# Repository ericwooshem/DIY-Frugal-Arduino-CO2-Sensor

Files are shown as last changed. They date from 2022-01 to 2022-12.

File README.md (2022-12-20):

# DIY Frugal Arduino CO₂ Sensor Monitor

CC BY-NC-SA [Eric Woo-Shem](https://github.com/ericwooshem) & [Brian Woo-Shem](https://www.brianwooshem.com)

CO2 Sensor Several Different Makes CO2 Data Graph

## Features

- Displays the current CO₂ level so you can quickly check if the current conditions are safe. 
- Records CO₂ levels over time. Good for tracking regularly-scheduled events (eg. school & work). 
- Accurate within ~60 ppm under typical conditions.
- Costs $60 to $110 - less than half the cost of commercial sensors.
- No soldering required! Just connect wires.

## Introduction: Why measure CO₂?

As society reopens amid the ongoing COVID-19 pandemic, preventing the spread of the virus is crucial to keeping doors open. Scientists and engineers studying aerosols at major research institutions have identified that good ventilation plays a major role in reducing contagion in addition to vaccines, regular testing, and masks [1]. Since [COVID-19 spreads primarily through airborne virus particles](https://www.science.org/doi/10.1126/science.abd9149), outdoor and well-ventilated areas are much safer because infectious particles blow away before they can be inhaled by a susceptible person. The challenge is identifying which spaces are poorly ventilated and could contain high concentrations of the virus.

Ideally, we would measure the concentration of COVID-19 virus particles in the air directly, however such a sensor does not exist. Instead, researchers identified [carbon dioxide as a proxy measurement](https://www.washingtonpost.com/health/2021/02/10/carbon-dioxide-device-coronavirus/) to determine if a space is well-ventilated, as doubling the CO₂ concentration doubles the risk of infection [2][3]. Humans exhale carbon dioxide at approximately 100 times the concentration of the ambient air. High CO₂ levels indicate inadequate ventilation so if a contagious person were present, virus particles remain in the air and there is a high risk that others in the space will get sick. 

The typical outdoor air CO₂ levels are between 410-420 ppm in remote locations, and around 450 ppm in urban environments [4][16]. We exhale roughly 40000 ppm CO₂ [5]. Aerosol researchers recommend keeping CO₂ below 800 ppm to prevent the spread of COVID-19 [1][2][3][6]. Aside from the pandemic, elevated CO₂ levels make a room feel “stuffy” and can cause a decline in cognitive ability [7]. CO₂ sensing is used in Heating, Ventilation, and Air Conditioning (HVAC) control and energy-saving thermostats to detect when a room is occupied and only operate air conditioning or heating during those times [14][15]. This can save energy by not running equipment while a building is unoccupied, while ensuring that people in the building have clean, healthy air [14].

# Instructions

### Parts

This is a *frugal* CO₂ sensor so most of the parts can be interchanged with similar ones. A detailed Bill of Materials with the exact components used in this version of the sensor is provided as "[CO2_Sensor_Bill_of_Materials.xlsx](https://github.com/ericwooshem/DIY-Frugal-Arduino-CO2-Sensor/blob/main/CO2_Sensor_Bill_of_Materials.xlsx)". Different sheets show suggestions for products to purchase for the lowest cost for varying numbers of sensors. The quantities and exact cost autocompute if you plug in the number of sensors you want to build. 

**Note:** Product suggestions in Bill of Materials are for convenience only. This project does not receive any incentive, financial or otherwise, for suggesting any particular product.

#### Cost

One sensor can be built for roughly $100, and 10 sensors for about $87 each if all parts are purchased new (As of August 2021).

#### List of Parts

| Part Description | QTY per Sensor |
|---|---|
| Arduino: Nano (recommended), Uno, Mega, etc. | 1|
|[SCD-30 NDIR CO2 Sensor](http://www.adafruit.com/product/4867)| 1|
|[STEMMA QT Cable Headers for SCD-30](http://www.adafruit.com/product/4209)|1|
|Breadboard: Mini breadboards recommended, but any size can work|1-2|
|Micro SD Card Adapter Module (Or SD Card Adapter Module)|1|
| Micro SD (or SD) Card. Small is fine - 1 GB is overkill|1|
|DS3231 Real Time Clock Module|1|
| CR2032 Battery|1|
|Jumper wires, assorted|10-20|
|USB Power Bank Battery 5V: optional; 9V battery adapter or other power supplies work as well|1|
|16x2 LCD Display: Optional; only needed if you want to display the current CO₂ levels|1|
|Small Box: Cardboard, 3D printed, etc. Just large enough to hold everything, and with holes for the CO₂ sensor intake and LCD screen if used|1|

## Assembly

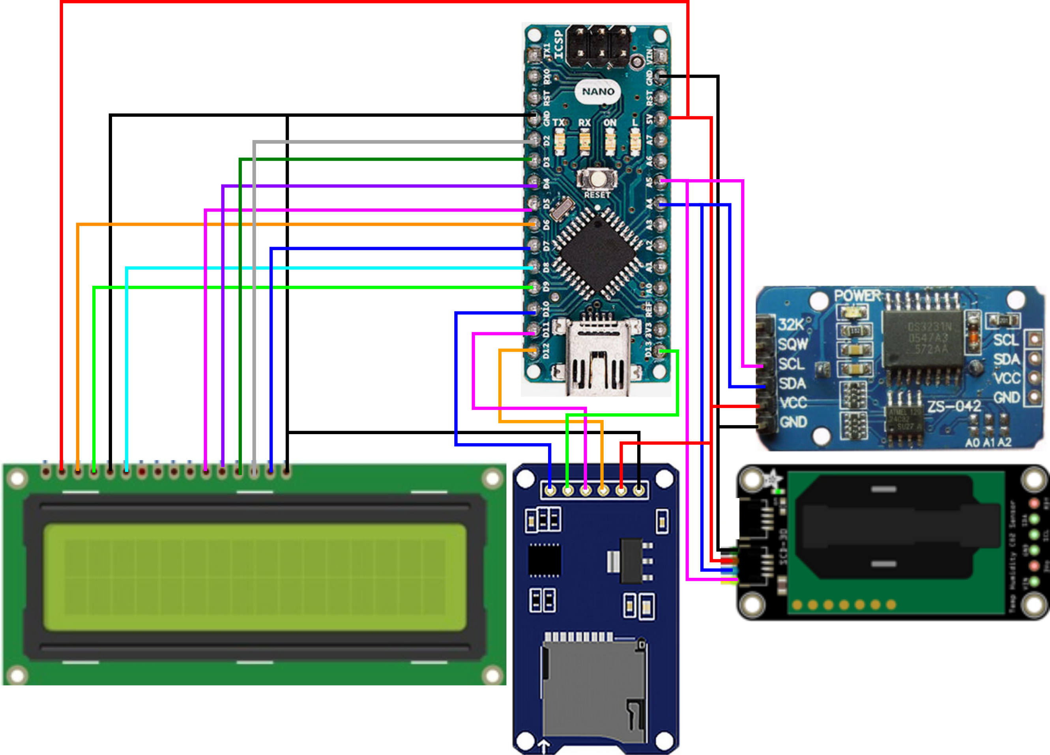
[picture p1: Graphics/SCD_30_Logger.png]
Connection Diagram


Complete connection diagram.

1. Insert the CR2032 battery into the RTC, and your memory card into your card reader.

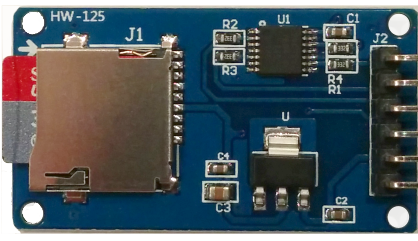
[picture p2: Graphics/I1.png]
Micro SD
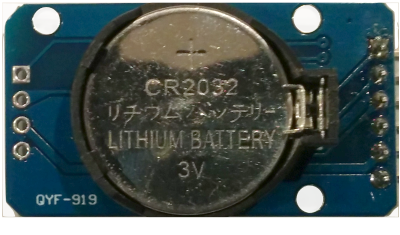
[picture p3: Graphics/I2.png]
RTC
	 

2. Attach 4 male-to-female wires onto the GND, VCC, SDA, and SCL ports on the RTC. If you have a new set of jumper wires, you may need to break them off of the bundle. Wire colors may vary.

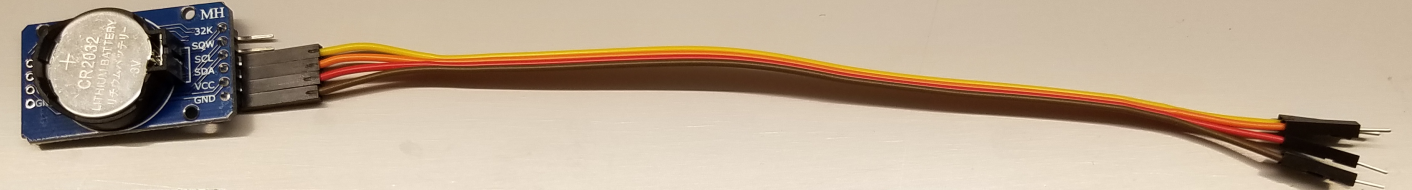
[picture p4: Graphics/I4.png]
	

3. Attach 6 male-to-female wires for all 6 pins on the card reader.

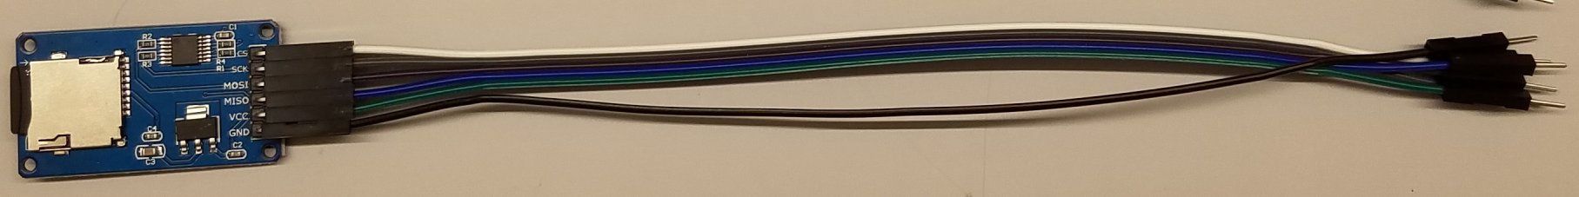
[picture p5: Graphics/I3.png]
Card Reader Wires
	

4. (For Nano only) Place and push in the Arduino Nano into one of the breadboards, as shown.

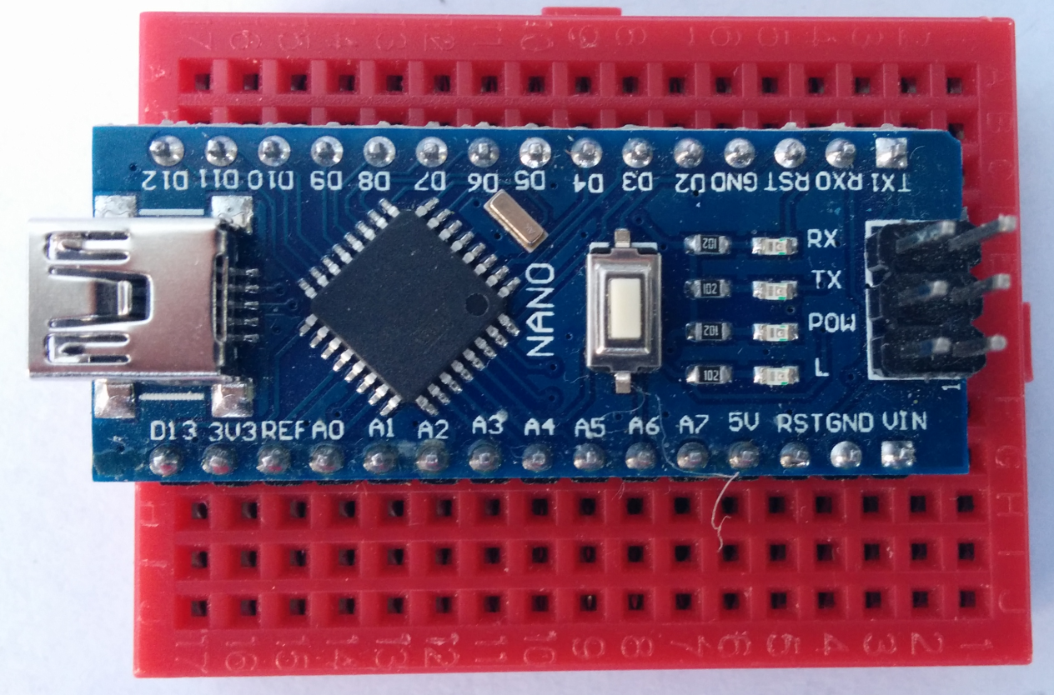
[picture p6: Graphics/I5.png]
Arduino Nano Breadboard
	

	- (For Uno or Mega) The connectors are built in, so this step is not necessary. However, you may need to run a wire from a particular pin to a breadboard row if more than one connection is required.  

5. Plug the SCD-30 cable headers into either port of the CO₂ sensor. Both ports are identical, but the plug has a correct orientation.

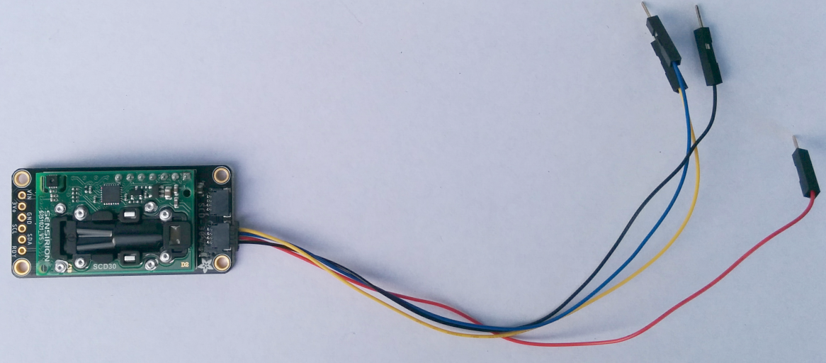
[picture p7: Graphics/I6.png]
SCD-30 Cable
	

6. (If using display) Poke the LCD into a breadboard. Mini-breadboards: use a second breadboard. Note: you can also use male-to-female wires and connect to the LCD pins directly, but we found this to be more difficult.

7. Connect the Ground on the Arduino to an unused row on the breadboard. Connect the 5V on the Arduino to a different unused row. Below is an example for mini-breadboards.

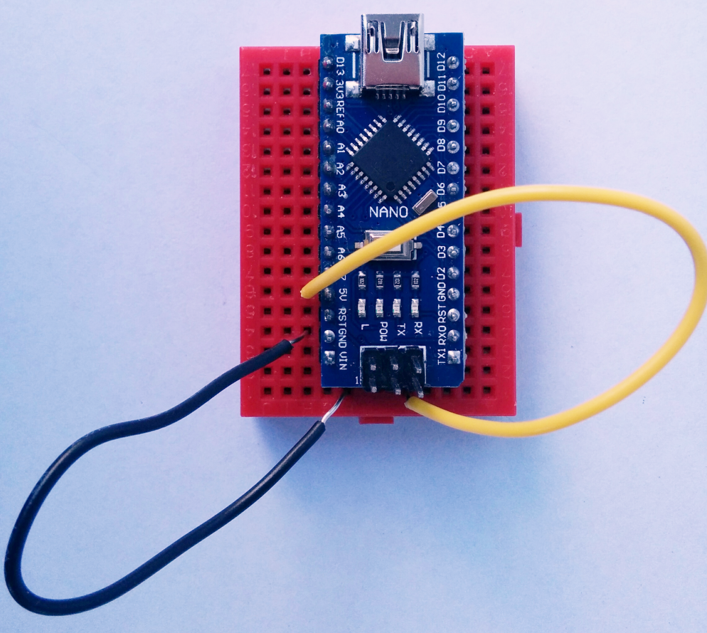
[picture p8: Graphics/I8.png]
Arduino-Breadboard
	

8. Connect the Real Time Clock module wires:

|Sensor Wire|Breadboard Row|
|---|---|
|VCC | 5V row created in step 7|
|GND | the ground row created in step 7|
|SDA | Arduino pin A4|
|SCL | Arduino pin A5|

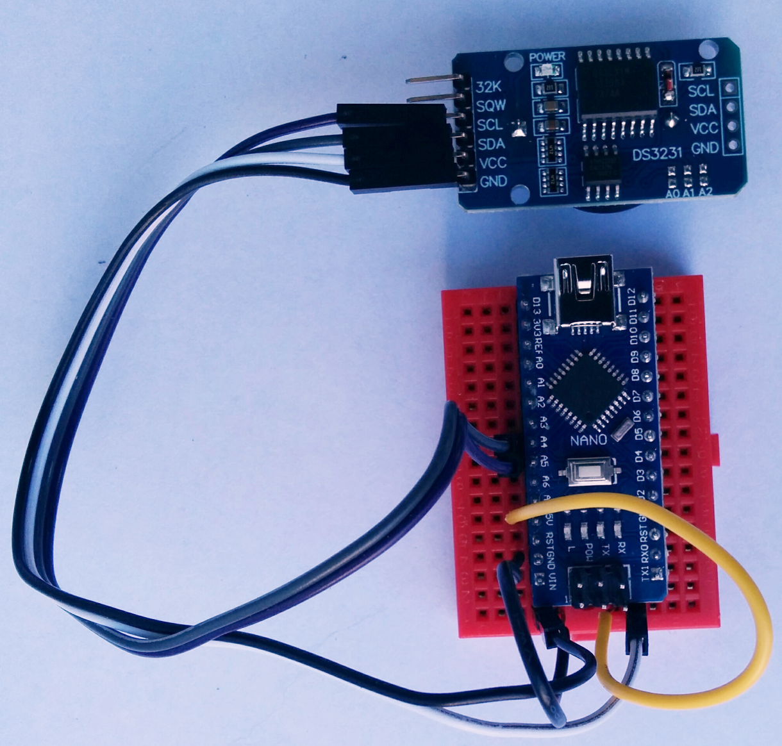
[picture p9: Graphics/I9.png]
   

9. Connect the SD Card Reader wires:

|Sensor Wire|Breadboard Row|
|---|---|
|GND |ground row created in step 7|
|VCC | 5V row created in step 7|
|MISO | Arduino pin D12|
|MOSI | Arduino pin D11|
|SCK | Arduino pin D13|
|CS | Arduino pin D10|

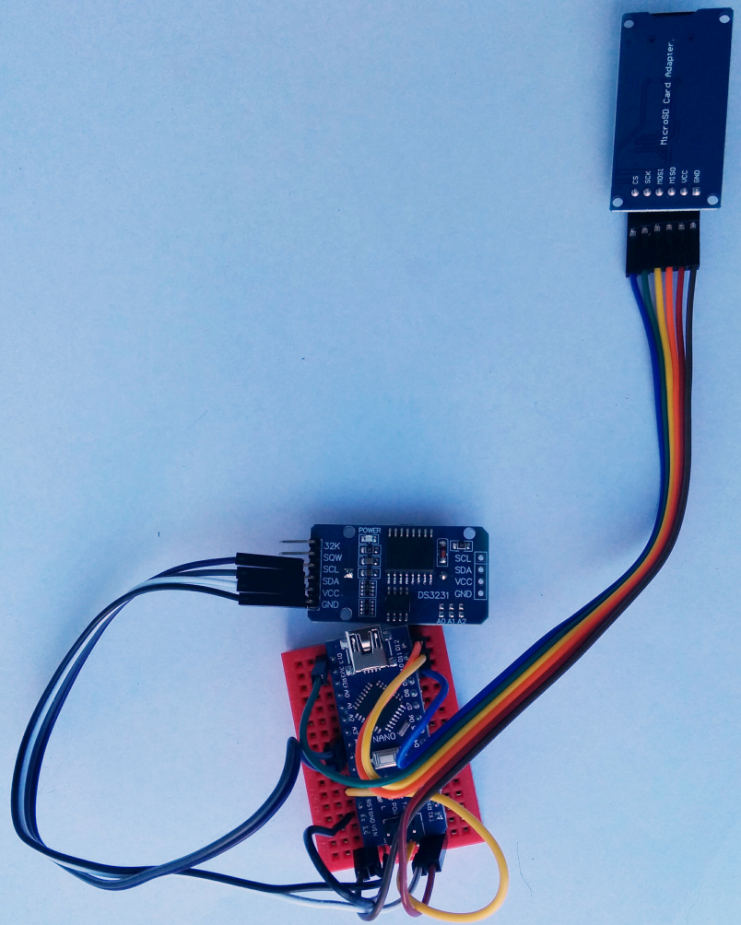
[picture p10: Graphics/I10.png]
SD Wires


10. Connect the SCD-30 Sensor wires:

|Sensor Wire|Breadboard Row|
|---|---|
|Black| ground row created in step 7|
|Red| 5V row created in step 7|
|Blue| Arduino pin A4|
|Yellow| Arduino pin A5|

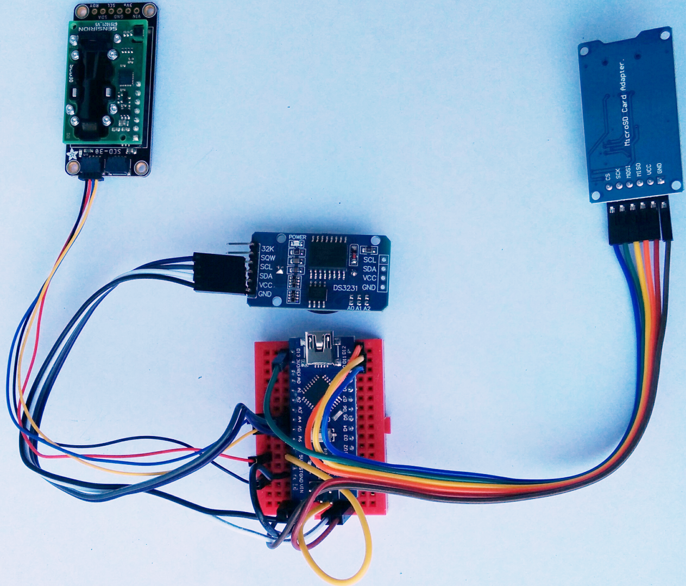
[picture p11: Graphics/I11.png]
SCD-30 Wires


11. Connect the LCD Wires: Short wires cut to length are preferred because they are more robust and make the device more compact. If using mini-breadboards, connect the LCD breadboard to the digital pin side of the Arduino breadboard using the little clip. Long wires are no longer recommended because they tend to get snagged and fall out. 

|LCD Pin Label|LCD Pin Position (Left to right)|Arduino Pin|
|---|---|---|
|VDD|2|5V|
|V0|3|D6|
|RS|4|D9|
|RW|5|Ground|
|E|6|D8|
|D4|11|D5|
|D5|12|D4|
|D6|13|D3|
|D7|14|D2|
|A|15|D7|
|K|16|Ground|

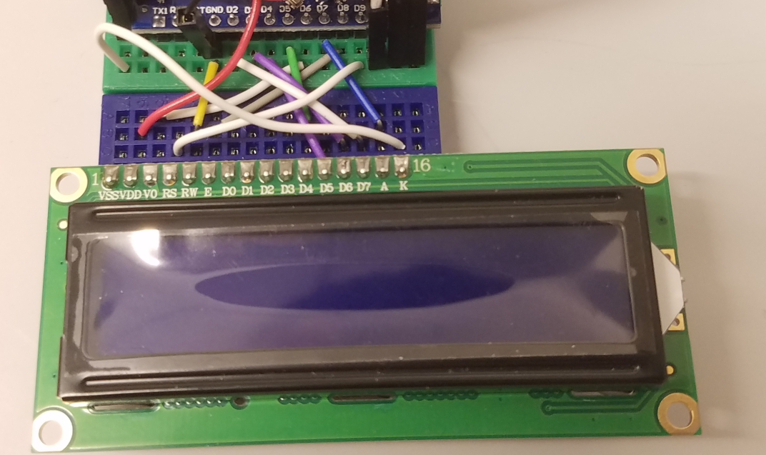
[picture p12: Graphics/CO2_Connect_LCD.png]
LCD to Arduino


Congratulations! The sensor is fully assembled. Now connect the Arduino to your computer and upload the program to use it.

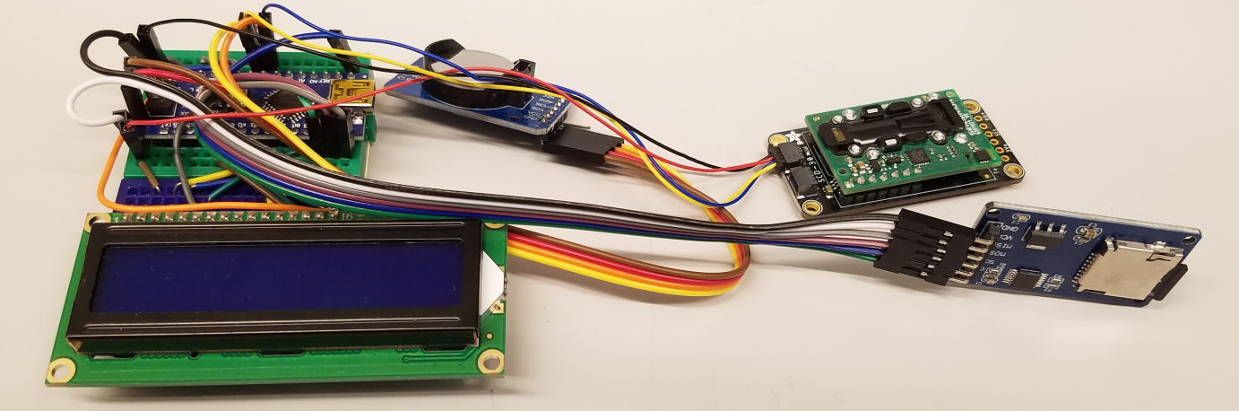
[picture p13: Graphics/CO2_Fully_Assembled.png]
Wiring Complete


## Uploading the Program

12. Connect the Arduino USB cable between the Arduino and your computer.

13. (If not already installed) Download [ArduinoIDE](https://www.arduino.cc/en/software/).

14. Set the time on the RTC (if not already set): Download the code file [*Set_RTC_Time.ino*](https://github.com/ericwooshem/DIY-Frugal-Arduino-CO2-Sensor/blob/main/Set_RTC_Time.ino) and open it in ArduinoIDE.

15. Go to Tools>Board and select your Arduino type.   

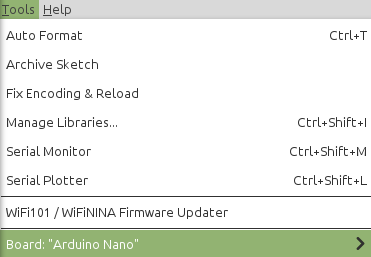
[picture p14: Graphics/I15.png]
Select board
	

16. (Arduino Nano only) Go to Tools>Processor and select "ATmega328P (Old Bootloader)".   

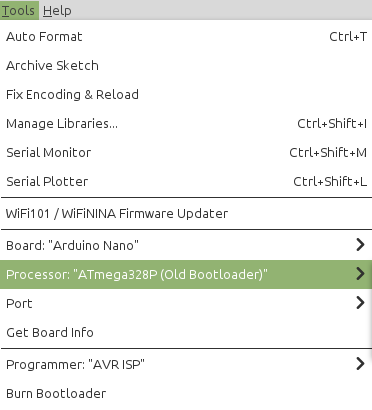
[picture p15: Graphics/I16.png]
Arduino Nano Processor
	

17. Go to Tools>Port, and select the one including the number “x”, equal to the port you plugged the Arduino into. If you are unsure which port, start with the first option and click “Get Board Info". If you get an error, it is the wrong one. Try the next port and repeat until one works. You can also try uploading the code on each port in step 20.

18. Go to Tools>Programmer, and select “AVR ISP”.   

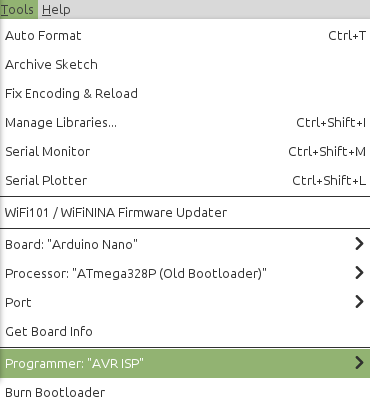
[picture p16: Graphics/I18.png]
AVR ISP
	

19. Install the necessary packages:
     1. Go to Tools>Manage Libraries. This may take a minute to load.   

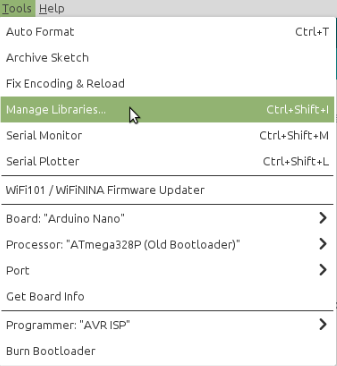
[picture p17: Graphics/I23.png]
Open Libraries Manager
           
	   
     2. Type "Adafruit_SCD30" into the search bar at the top and press enter. This may take a minute to load.
     3. Look for the package named "Adafruit SCD30". If the package isn't already installed, press the "Install" button. You may need to install dependencies.
     4. Repeat for RTClib (named "RTClib"). You may need to install "SD" and "LiquidCrystal", but those should be pre-installed.

20. In the [*RTC_Time_Set.ino*](https://github.com/ericwooshem/DIY-Frugal-Arduino-CO2-Sensor/blob/main/Set_RTC_Time.ino) code, go to line 19 with the code `rtc.adjust(DateTime(2021, 10, 13, 18, 17, 00));`. Change the numbers to match the form '(Year, month, day, hour in 24 hour time, minute, second)' for the current date and time. The RTC module will be set to the time specified when you upload the code. Tip: If you want very precise time, set the minutes and seconds for about a minute out, then watch the clock and hit upload about 4-6 seconds before the time you set. However, within ~5 minutes is usually good enough.
     1. Alternative method: A different code from [Arduino Get Started](https://arduinogetstarted.com/tutorials/arduino-rtc) can automatically set the RTC to the time on your computer; follow the instructions at that link to set the RTC.

21. Upload the program to the Arduino by clicking on the right arrow button next to the check mark button. Warning: Do not touch until it says, "Done uploading."   
	Arduino Upload Code

22. Upload the CO₂ sensor code: Download [*CO2SensorCode.ino*](https://github.com/ericwooshem/DIY-Frugal-Arduino-CO2-Sensor/blob/main/Co2SensorCode.ino) and open it in Arduino IDE. Upload the program to the Arduino by clicking on the arrow button next to the check mark button.

23. Plug the Arduino into a computer, USB Power Bank, or other power supply to turn the sensor on. Whenever it is given power, the sensor system will display the current CO₂ readings on the screen and save them to a file on the SD card.

# Troubleshooting

[Arduino IDE / Code Upload Issues](https://support.arduino.cc/hc/en-us/articles/4403365313810-Errors-when-uploading-a-sketch)   
[Arduino Nano Select Processor](https://support.arduino.cc/hc/en-us/articles/4401874304274-Select-the-right-processor-for-Arduino-Nano)   
[Wiring Intro for Beginners](https://learn.adafruit.com/breadboards-for-beginners/introduction)    
[SCD-30 Sensor](https://learn.adafruit.com/adafruit-scd30)   
[Alternative Method to Set Date and Time on RTC](https://create.arduino.cc/projecthub/tittiamo68/clock-set-date-time-0d46a4) Note: Use the LCD wiring from this project instead.  
[Intro to SD and Micro SD Card Modules with Arduino](https://create.arduino.cc/projecthub/electropeak/sd-card-module-with-arduino-how-to-read-write-data-37f390)  

### Arduino to computer connection not working / code won't upload

- Check [Arduino IDE / Code Upload Issues](https://support.arduino.cc/hc/en-us/articles/4403365313810-Errors-when-uploading-a-sketch)
- Try each port option
- Try each processor option
- Swap the USB cable with another - sometimes the cables break
- Try a [Loopback Test](https://support.arduino.cc/hc/en-us/articles/360020366520-How-to-do-a-loopback-test)

### Most components appear to work, but one does not

- Most likely this is a wiring issue. Check that the wires leading to that component are matched to the correct pins and firmly attached.
- Re-upload the sensor code.
- Try a different power supply. If the current one is too weak, some components may work but others will not have enough power to operate.

### Sensor returns ridiculously large or small readings

- Anything between 400 ppm outdoors or in well-ventilated areas to 4000 ppm in stuffy buildings and inside cars is probably valid.
- If the first value is 0, this is a known bug. Simply ignore that value.
- Check that the cable is firmly plugged into the sensor, and the wires are properly connected to the breadboard and Arduino.
- Try swapping the cable to the other port on the SCD-30 sensor.

# Monitor Usage Tips

- The sensor is sensitive to wind; it works best to place it slightly inside the cases or place a small piece of paper between the sensor and the opening. 
- Do not seal the container entirely; the sensor will not have access to the current air conditions.
- The sensor can be placed in a backpack/purse with a small (~3") opening left in the zipper so that air can circulate through. 
- Do not crush the sensor by mistake. Keep it on top of any heavy objects like books and lunchboxes.
- Save your data and compare the average value at each location to the acceptable limit.
- If you know your schedule, you can match your recorded data to each specific location.
- Download the data file and delete it from the SD card after you use the sensor each day so that you can more easily keep track of your data and where you collected the data. Otherwise the data file gets large and cumbersome.

## Accessing and Using Collected CO₂ Data

When using the sensor, you can simply read the values from the screen. However, to get a more complete picture of how safe each place is, it is necessary to analyze the data for the entire time you are there. You can upload the data to your computer from the (micro) SD card, put it into a spreadsheet program, and create graphs or analyze it.

1. Remove the (Micro) SD card from the adapter module by pressing firmly and releasing until it springs out, then pulling it out gently. 
2. Connect the (Micro) SD card to your computer, using adapters if necessary.
3. Copy the file on the card “CO2_Data.TXT” to your computer. The file is structured as follows:   
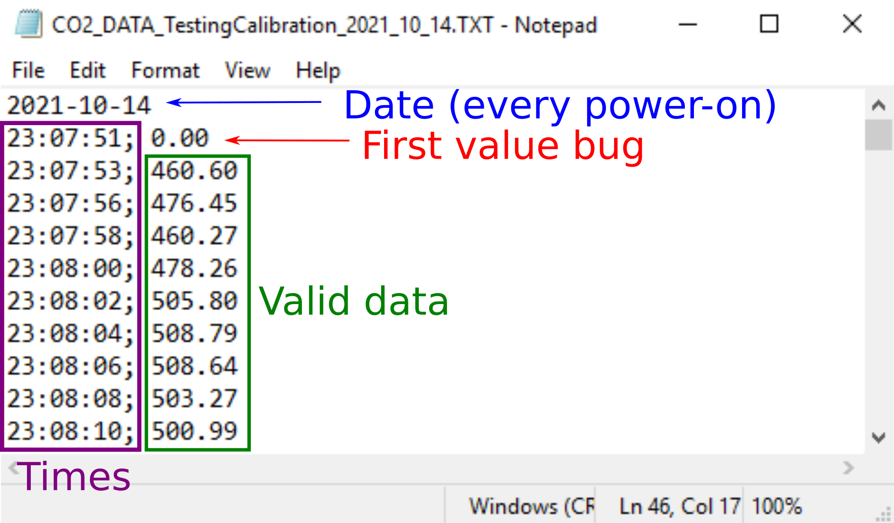
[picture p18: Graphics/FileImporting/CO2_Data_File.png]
CO2 Data File
	   
4. Typically, we want to import the data to a spreadsheet software like Excel or Google Sheets. We also want the times and the CO2 readings separated for so we can plot the values and compare over time. See the instructions below for your specific software. 

### Text File Modification: Google Sheets or Microsoft Excel (Advanced, almost always works)
1. Open the _.txt_ file in a text editor.  
2. Use Find & Replace, Finding ";" (semicolon) and Replace with "," (comma). _Optional: to separate the hours, minutes, and seconds into three separate columns for doing calculations like time elapsed from the start or to convert it to another date-time format, in addition Find ":" (colon), and replace with "," (comma)._   
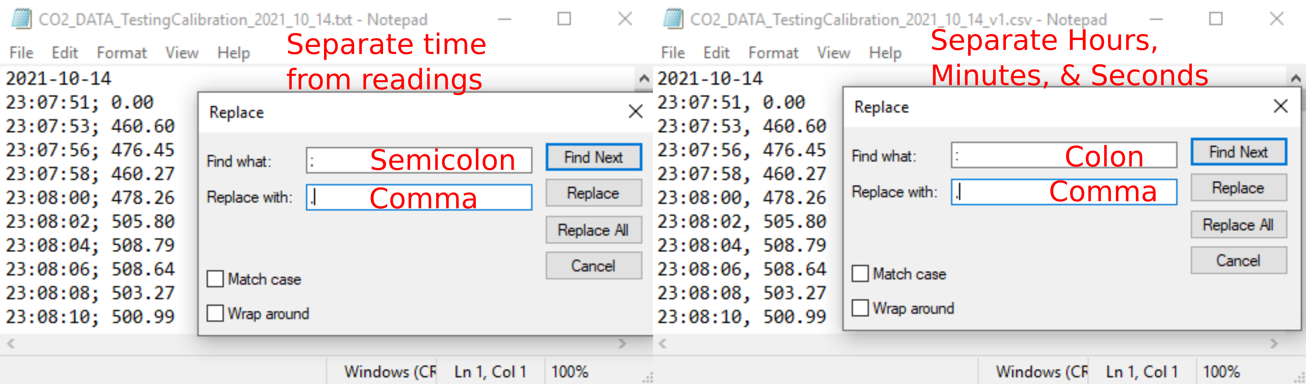
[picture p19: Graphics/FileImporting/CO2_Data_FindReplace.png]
Find Replace 1
	   
3. The file will now look as follows. Left: only times and readings. Right: times separated into hours, minutes, and seconds, with readings also separated.   
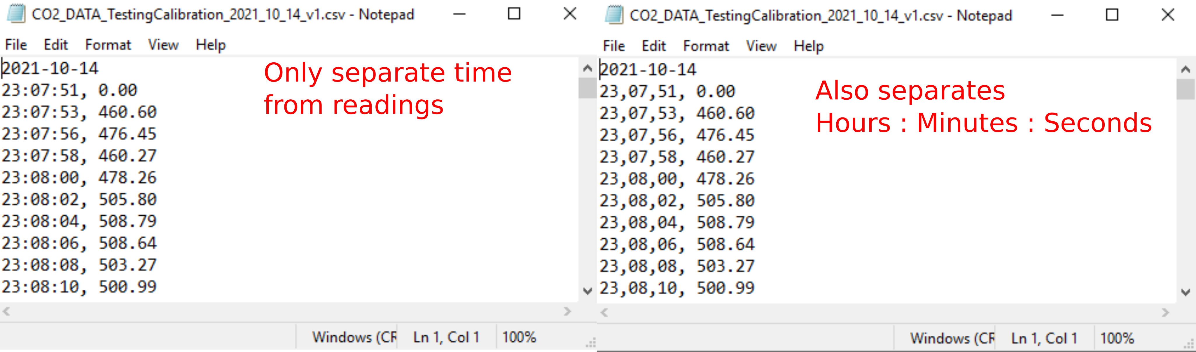
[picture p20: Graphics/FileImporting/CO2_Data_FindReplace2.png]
Find Replace 2
	   
4. Change the file extension to _.csv_ (on Windows [see instructions below](https://github.com/ericwooshem/DIY-Frugal-Arduino-CO2-Sensor#windows-changing-file-extension-to-csv))
5. Open with your favorite spreadsheet software. Example results:
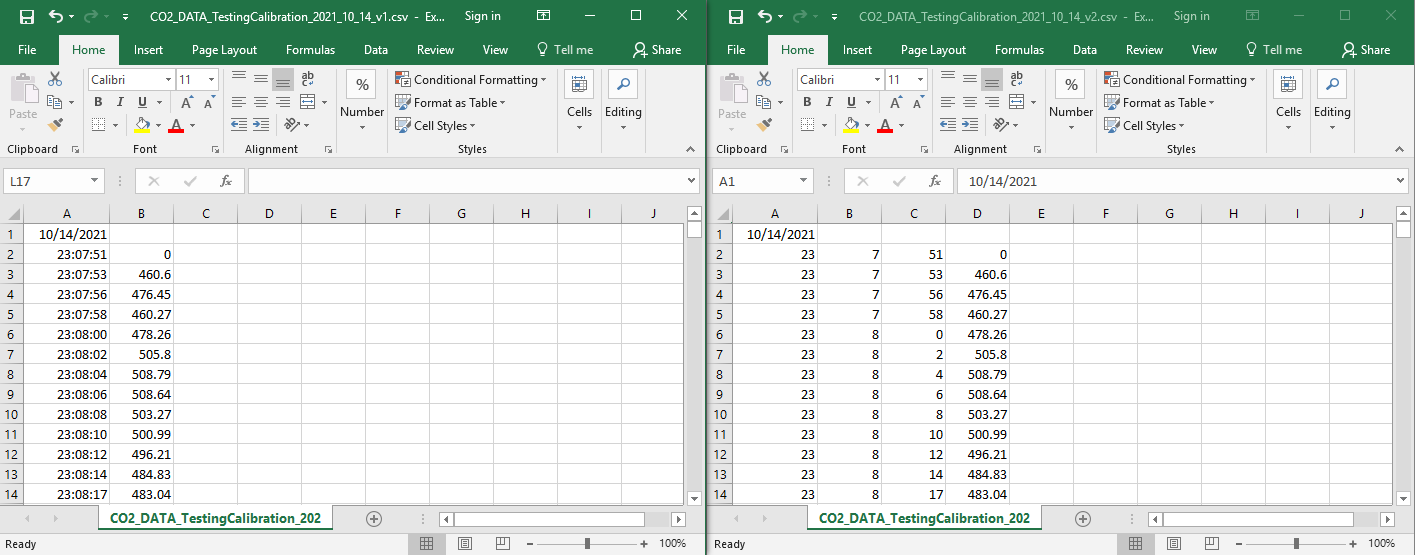
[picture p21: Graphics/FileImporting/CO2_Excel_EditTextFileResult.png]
Example text file modification results in Excel
	

### Microsoft Excel Text Import Wizard (Shortcut, sometimes works)
1. Open Excel
2. Go to the "Data" tab and select "From Text"   
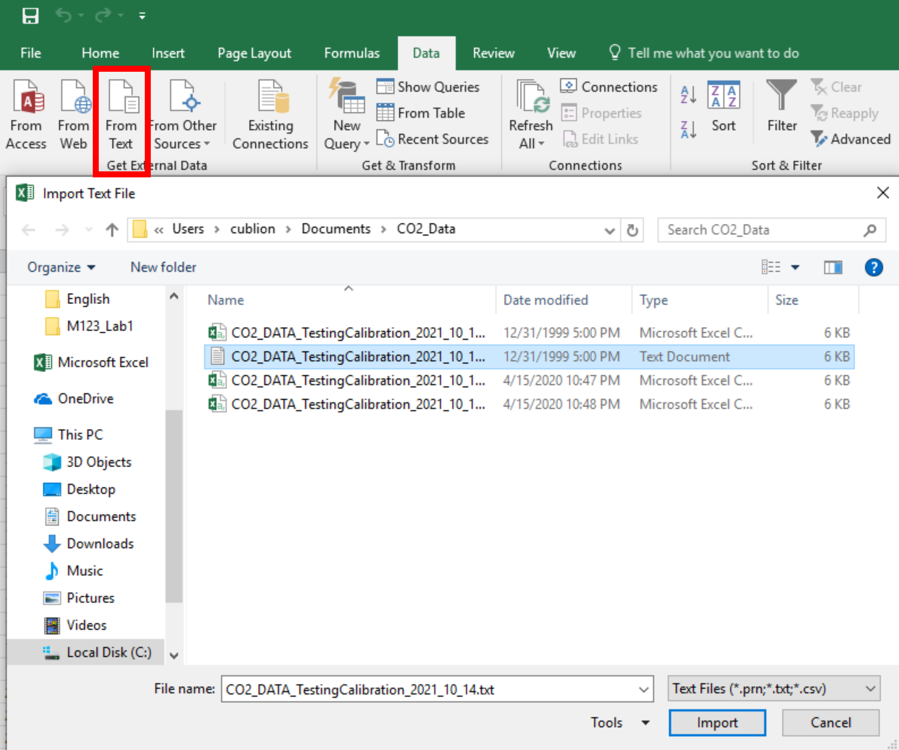
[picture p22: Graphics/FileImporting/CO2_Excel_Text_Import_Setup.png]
Excel Text Import 1
	   
3. Follow the Text Import Wizard. Make sure to select "Delimited" on the first step, and include "Semicolon" on the list of delimiters on the second step.   
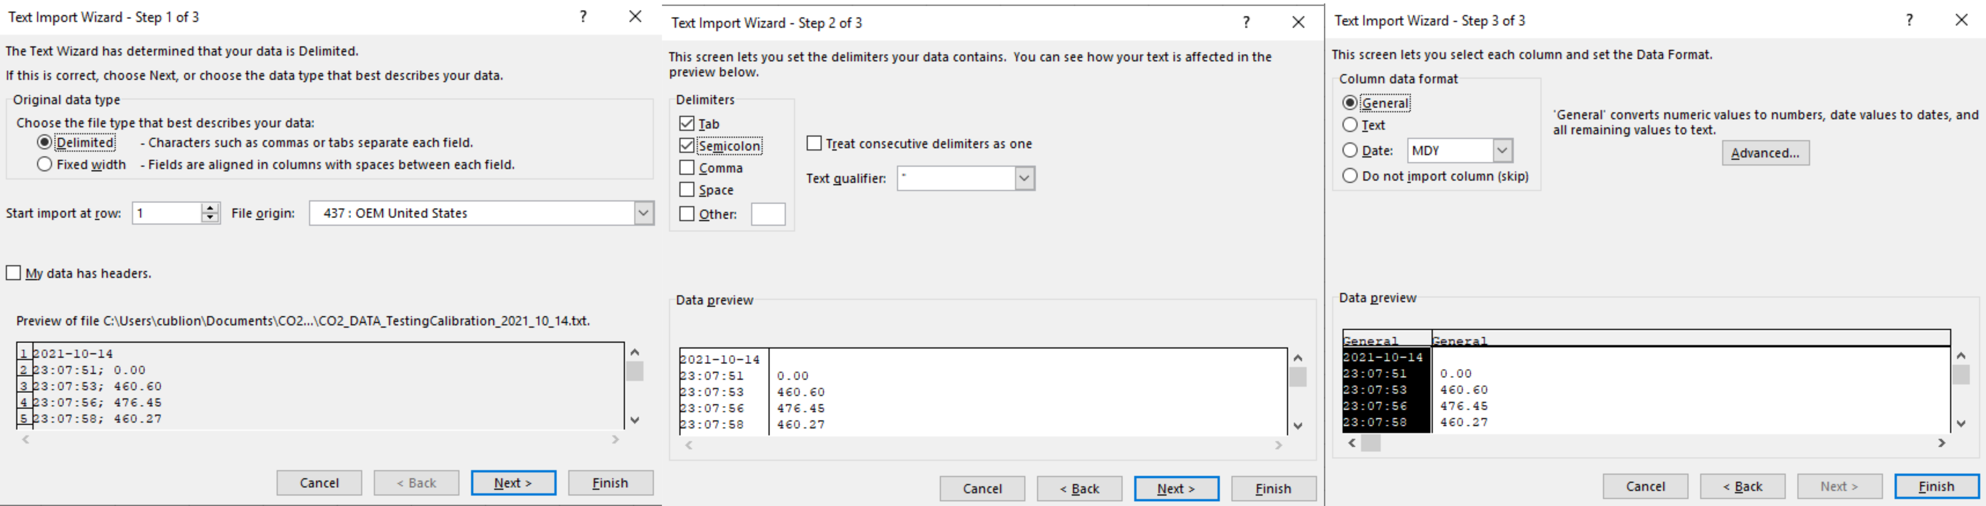
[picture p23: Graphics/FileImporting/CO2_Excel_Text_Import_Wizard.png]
Excel Text Import Wizard
	    
4. Data will now be in two columns, one for time and one for the sensor readings.

### LibreOffice
1. Change the file extension to _.csv_ (on Windows [see instructions below](https://github.com/ericwooshem/DIY-Frugal-Arduino-CO2-Sensor#windows-changing-file-extension-to-csv))
2. Open with LibreOffice. You may need to right click then select "Open with" and choose your spreadsheet software if the computer defaults to another application.
3. Choose Semicolon in the Text Import window, then click OK. The data will be imported.   
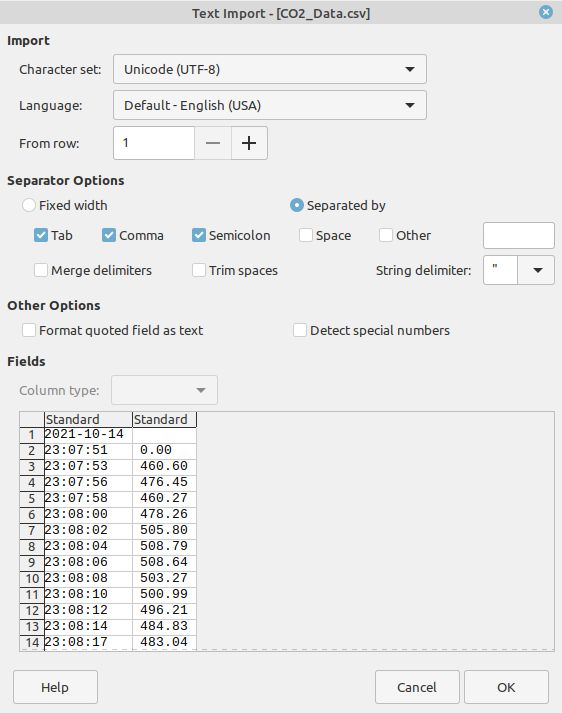
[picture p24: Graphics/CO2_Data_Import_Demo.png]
Data import demo
	

### Windows - Changing file extension to CSV
1. If the file extension (_.txt, .csv_, etc.) is not visible in File Manager, go to "View" tab and check "File name extensions"    
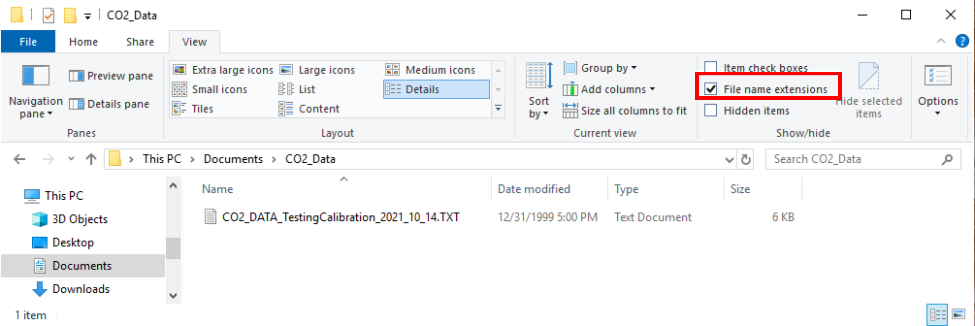
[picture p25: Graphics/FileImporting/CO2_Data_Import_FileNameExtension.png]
File Name Extensions Windows
	   
2. Rename the file to have _.csv_ at the end instead of _.txt_    
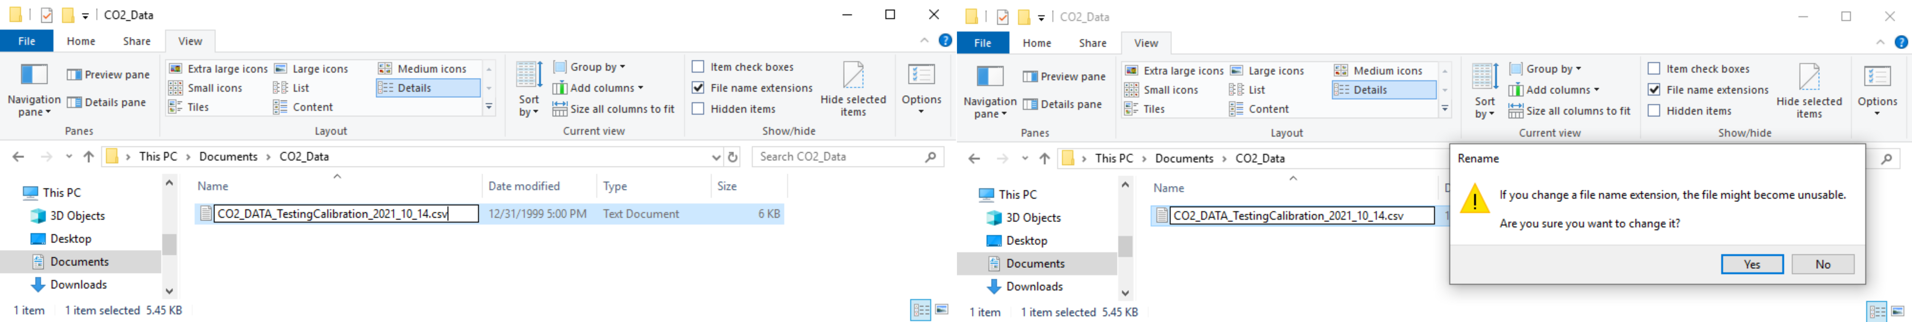
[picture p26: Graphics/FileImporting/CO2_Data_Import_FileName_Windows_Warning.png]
File Renaming Windows
	   
3. If you get a warning, select "Yes."

### Data Analysis Tricks

- To save your graphs, "Save As" and choose _.xls_, _.xlsx_, or _.ods_ file formats.
- To get time elapsed, convert HH:MM:SS to separate columns for hours, minutes, and seconds using the detailed instructions under "Text File Modification." Insert a new column between Seconds and CO2 [ppm]. If all zero values, date lines, and other garbage data have been removed, and there is a single header row, paste the following line of code in D2.    

        =C2+B2*60+A2*3600-($C$2+$B$2*60+$A$2*3600)   

	- then select `Ctrl + D` and apply it to all the rest of the rows. The result will look something like this:    
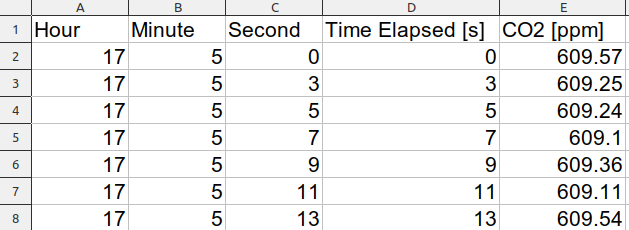
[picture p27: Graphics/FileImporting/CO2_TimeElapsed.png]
Time elapsed
		

- The first data point is recorded as 0 because the Arduino tries to record data before the initial reading is complete. This is incorrect and should be deleted.
- Every time the Arduino is powered off and restarted, it will append the initial set of data but add a new line with the date in the form YYYY-MM-DD. 
	- Sometimes the sensor gets bumped and restarts unexpectedly. Searching for "-" can detect these errors. The date line needs to be removed before graphing.
	- If you use the sensor for several days between downloading the data, look for these date lines to figure out when each chunk of data was collected.
	- If the sensor is left on continuously past midnight, it will not create a new date line but simply jump to 00:00:00.

# Testing & Validation

- Outside away from people and buildings, the sensor should read between 400 and 500 ppm.
- If you breathe directly on the sensor, it should read over 10,000 and up to 40,000.
- The sensor is very sensitive to nearby sources of CO₂. For example, we observed that the sensor reads 500-550 ppm when we walk outside with it in our backpack because our breath is enough to raise the CO₂ levels locally.
- The sensors come pre-calibrated if ordered from Adafruit. Out of 25 sensors we tested, most were within spec but a few were as low as 300ppm or as high as 660ppm without calibration. Use the calibration code for a single sensor, or assemble the [calibration tool](https://github.com/bwooshem/SCD-30-CO2-Sensor-Calbiration-Tool) for calibrating many sensors quickly.

## Comparison to Aranet Sensor

A company called Aranet produces CO₂ sensors that are ready to use out of the box. Many researchers have recommended them. Here's how our DIY sensor compares.

|  |[Adafruit SCD-30](https://www.adafruit.com/product/4867) [12]|[Aranet4](https://www.co2meter.com/products/aranet4-home-indoor-air-quality-monitor) [13]|
|---|---|---|
|Range:|400-10000ppm|0-9999ppm
|Accuracy:|±30 ppm + 3%|0-2000ppm: ±50ppm ± 3% reading  <br> 2001-9999ppm: ±10% of reading |
| | | |
|Accuracy At:  |
|	420ppm (outside)|	±42.6ppm|±62.6ppm|
|	800ppm	|±54 ppm|±74ppm|
|	1000ppm|±60 ppm|±80ppm|
|	2000ppm|±90 ppm|±110ppm|
|	3000ppm|±120 ppm|±300ppm|
| | | |
|Fastest supported measurement interval: 	|2 seconds|1 minute|
|Length of stored measurement data at fastest measurement interval|	>30 days/GB-SD*|3.5 days|
|Accuracy of other measurements:
|Temperature:|±0.3 °C|±0.3 °C
|Rel. Humidity: |± 2 %|± 3 %
| | | |
|Atmospheric Pressure: 
|Range: |Not included|0.3 to 1.1 atm (4.4 to 16.0 psi)|
|Accuracy:|N/A|± 1 hPa|
| | | |
|Battery Type:|Rechargeable USB|2 x AA|
|Battery Life:|~3 days|Up to 2 years|
|Cost:|est $60-110|$249|

\* Multiply by the size in GB of micro SD card

## Contributors
[Eric Woo-Shem](https://github.com/ericwooshem): Sensor design, assembly documentation/electrical diagrams/visualizations, programming: sensor firmware/calibration/RTC time set, component selection.

[Brian Woo-Shem](https://www.brianwooshem.com): Engineering guidance, research, documentation, data analysis, [educational curriculum development](https://www.brianwooshem.com/co2-sensor-lab/), sensor testing and validation.

Thank you to the [Santa Clara University Department of Mechanical Engineering](https://www.scu.edu/engineering/academic-programs/department-of-mechanical-engineering/) for providing photos of sensor builds and feedback from students when this project was adapted into a [laboratory for the Modern Instrumentation course](https://www.brianwooshem.com/co2-sensor-lab/).

## License

All text, graphics, and non-code content is licensed [CC BY-NC-SA](https://creativecommons.org/licenses/by-nc-sa/4.0/)    
All code is licensed under the [GNU General Public License v3](https://www.gnu.org/licenses/gpl-3.0.en.html)

RTClib and Adafruit_SCD30 are Copyright (c) Adafruit Industries and used under the open source MIT license.   
Arduino IDE and related components are open source and licensed under the GNU GPL v2 and/or CC BY-SA Arduino.

## References

[1] Wang et al., Science Vol 373, Issue 981 (2021). https://www.science.org/doi/10.1126/science.abd9149   
[2] Z. Peng and J. Jimenez, “Exhaled CO₂ as a COVID-19 Infection Risk Proxy for Different Indoor Environments and Activities, ACS, 2021. https://pubs.acs.org/doi/10.1021/acs.estlett.1c00183   
[3] C. Mooney, “The Coronavirus is Airborne. Here’s How to Know if You’re Breathing Other People’s Breath,” The Washington Post, 2021. https://www.washingtonpost.com/health/2021/02/10/carbon-dioxide-device-coronavirus/   
[4] NOAA Global Monitoring Laboratory, “Trends in Atmospheric Carbon Dioxide.” https://gml.noaa.gov/ccgg/trends/   
[5] K. Alhambra and D. Czernia, CO₂ Breathing Emission Calculator. https://www.omnicalculator.com/ecology/co2-breathing-emission   
[6] UK Health and Safety Executive, Ventilation and Air Conditioning During the Coronavirus Pandemic.
 https://www.hse.gov.uk/coronavirus/equipment-and-machinery/air-conditioning-and-ventilation/identifying-poorly-ventilated-areas.htm   
[7] V. Greenwood, "Is Conference Room Air Making You Dumber?" The New York Times, 2019. https://www.nytimes.com/2019/05/06/health/conference-room-air.html   
[8] Adafruit SCD-30 Resources. https://learn.adafruit.com/adafruit-scd30   
[9] G. Lambert, "How to Write Data to Files on an SD Card with Arduino," Circuit Basics. https://www.circuitbasics.com/writing-data-to-files-on-an-sd-card-on-arduino/   
[10] "Arduino - RTC" Arduino Get Started. https://arduinogetstarted.com/tutorials/arduino-rtc   
[11] Adafruit RTClib, GitHub. https://github.com/adafruit/RTClib/tree/master/examples    
[12] Adafruit, "Adafruit SCD-30 - NDIR CO2 Temperature and Humidity Sensor - STEMMA QT / Qwiic." https://www.adafruit.com/product/4867   
[13] CO2Meter.com, "Aranet4 HOME Indoor Air Quality Monitor" https://www.co2meter.com/products/aranet4-home-indoor-air-quality-monitor   
[14] CO2Meter.com, "CO2 Sensors Improve Energy Efficiency in HVAC," 2022. https://www.co2meter.com/blogs/news/co2-sensors-hvac-energy-efficiency   
[15] Honeywell, "Carbon Dioxide (CO₂) HVAC Basics," 1998. https://customer.honeywell.com/resources/Techlit/TechLitDocuments/63-0000s/63-7049.pdf  
[16] Aclima [Air.health](https://air.health/): Look up CO₂ levels for any address in the San Francisco Bay Area.

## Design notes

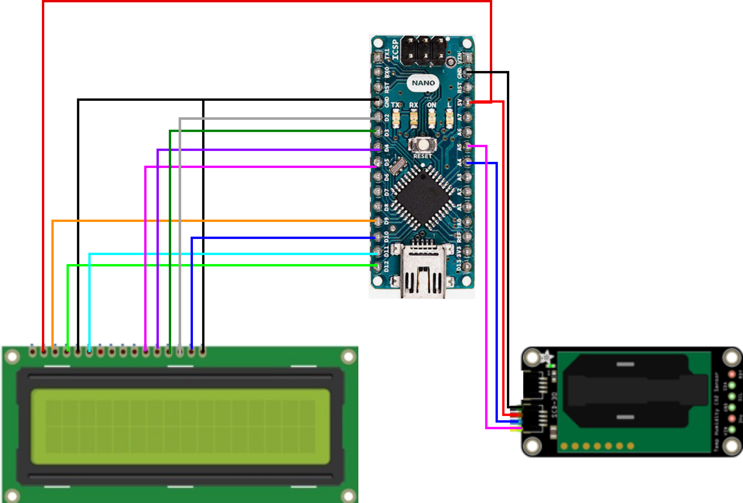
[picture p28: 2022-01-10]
Graphics/SCD_30_Base.png

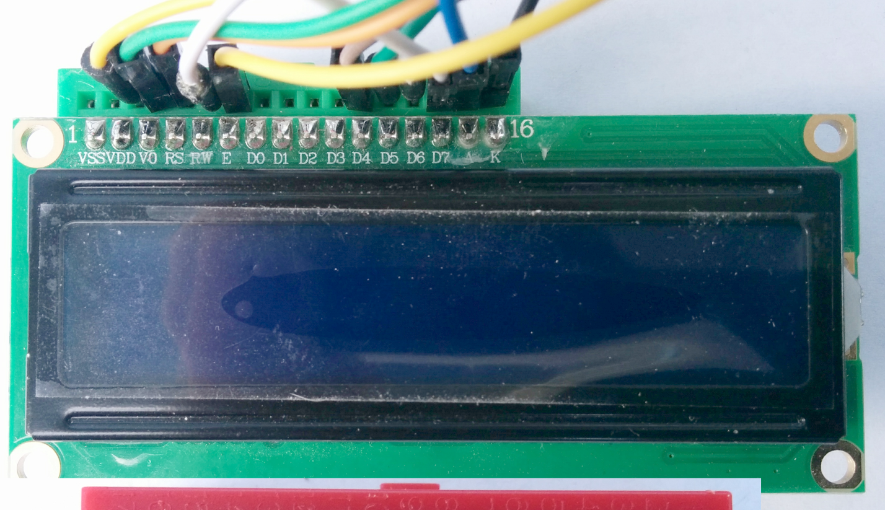
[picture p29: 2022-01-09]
Graphics/I7.png

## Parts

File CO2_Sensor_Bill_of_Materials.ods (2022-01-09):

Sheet: Intro
DIY Arduino Frugal CO2 Sensor
Bill of Materials
CC By-NC Brian & Eric Woo-Shem
Updated: 2022-01-08
Instructions:
1. Choose the sheet corresponding to the number of units you want to make. The options are 1 unit, 2-9 units, and >= 10 units
2. Change the number of units in the cell below "Enter number of sensors:" (A17) to match how many you want
3. Price and quantity cells will auto-populate
4. Purchase the number of packages (set of one or more parts sold together) on the vendor websites equal to the "QTY to Purchase" column (J)
Note that most of the other columns are for calculations and can be ignored.
The "Extra" column shows how many extra parts are left over for that number of sensors.
Note: For certain quantities, it can be less expensive to purchase parts for extra sensors because of bulk discounts

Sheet: 1 Unit
CO2 Sensor Bill of Materials | Optimized for manufacture of 1 Unit |  |  | Prepared by Brian Woo-Shem and Eric Woo-Shem
Item | Vendor | Qty Included | Qty per Sensor | Product Cost | Sensor Cost | Per Part Cost | Req? | #Sens | QTY to Purchase | Extra | URL | Notes
Arduino Nano (Generic) | Ebay | 1 | 1 | $6.75 | $6.75 | $6.75 | 1 | 1 | 1 | 0 | ebay.com/itm/383962331050 | Microcontroller
Mini Breadboard | Ebay | 6 | 2 | $4.95 | $1.65 | $0.83 | 1 | 3 | 1 | 2 | www.ebay.com/itm/221938873679 | Arduino pin base (avoid soldiering)
SCD-30 NDIR CO2 Sensor | Adafruit | 1 | 1 | $58.95 | $58.95 | $58.95 | 1 | 1 | 1 | 0 | www.adafruit.com/product/4867 | Sensor
STEMMA QT Cable Headers for SCD-30 | Adafruit | 1 | 1 | $0.95 | $0.95 | $0.95 | 1 | 1 | 1 | 0 | www.adafruit.com/product/4209 | Cable specific to this sensor (avoid soldiering)
Micro SD Card Adapter Module + cables | Amazon | 3 | 1 | $6.99 | $2.33 | $2.33 | 1 | 3 | 1 | 2 | amzn.com/B08XPFYBYT | Adapter for card recording sensor data and connects to computer to get logged data | Note no jumper wires because SD and RTC contain enough for 1 sensor
DS3231 Real Time Clock Module + Cables | Ebay | 1 | 1 | $3.09 | $3.09 | $3.09 | 1 | 1 | 1 | 0 | www.ebay.com/itm/324345358969 | Tracks time to correspond to data
CR2032 Battery | Ebay | 2 | 1 | $1.98 | $0.99 | $0.99 | 1 | 2 | 1 | 1 | www.ebay.com/itm/282998642500 | Power for Real Time Clock
Micro SD Memory Card | Amazon | 1 | 1 | $6.79 | $6.79 | $6.79 | 1 | 1 | 1 | 0 | amzn.com/B07SNSXNSX | Records sensor data and connects to computer to get logged data
USB Power Bank Battery 5V | Ebay | 1 | 1 | $2.54 | $2.54 | $2.54 | 0 | 1 | 1 | 0 | www.ebay.com/itm/124739332639 | Rechargable power supply for Arduino and Sensor, allows for operation without connection to wall socket or computer. | For faster delivery, we recommend a domestic vendor such as Amazon. The following link is $10.99 each. | http://amzn.com/B08QHG1SWY
[Optional] 16x2 LCD Display | Adafruit | 1 | 1 | $10.95 | $10.95 | $10.95 | 0 | 1 | 1 | 0 | www.adafruit.com/product/1447 | Display to show current reading without connecting to computer. Optional because sensor functions without this part but students may find it helpful to have instant feedback.
Small Box | DIY / Maker Lab | 1 | 1 | $0.00 | $0.00 | $0.00 | 0 | 1 | 1 | 0 |  | Housing to protect sensor and components. 3D print or build out of cardboard. May also cut holes in small (~12*10*4cm) cardboard box. Design may vary.
 |  |  | Cost Per Sensor |  | $94.99 |  |  |  |  |  |  | Complete Sensor
ENTER QTY |  |  | Cost of Required Components |  | $81.50 |  |  |  |  |  |  | Only the parts needed to get a barebones setup working off of a computer.
1
 |  |  | Total Cost |  | $103.94
 |  |  | Extra Part Value |  | $7.30

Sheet: 2-9 Units
CO2 Sensor Bill of Materials | Optimized for manufacture of 2-9 Units |  |  | Prepared by Brian Woo-Shem and Eric Woo-Shem
Item | Vendor | Qty Included | Qty per Sensor | Product Cost | Sensor Cost | Per Part Cost | Req? | #Sens | Qty to Purchase | Extra | URL | Notes
Arduino Nano (Generic) | Amazon | 3 | 1 | $16.99 | $5.66 | $5.66 | 1 | 3 | 3 | 2 | amzn.com/B07G99NNXL | Microcontroller
Mini Breadboard | Amazon | 12 | 2 | $8.05 | $1.34 | $0.67 | 1 | 6 | 2 | 5 | amzn.com/B08BHRVGMN | Arduino pin base (avoid soldiering)
SCD-30 NDIR CO2 Sensor | Adafruit | 1 | 1 | $58.95 | $58.95 | $58.95 | 1 | 1 | 7 | 0 | www.adafruit.com/product/4867 | Sensor
STEMMA QT Cable Headers for SCD-30 | Adafruit | 1 | 1 | $0.95 | $0.95 | $0.95 | 1 | 1 | 7 | 0 | www.adafruit.com/product/4209 | Cable specific to this sensor (avoid soldiering)
Micro SD Card Adapter Module | Amazon | 3 | 1 | $6.99 | $2.33 | $2.33 | 1 | 3 | 3 | 2 | amzn.com/B08XPFYBYT | Adapter for card recording sensor data and connects to computer to get logged data
DS3231 Real Time Clock Module | Amazon | 5 | 1 | $14.25 | $2.85 | $2.85 | 1 | 5 | 2 | 3 | amzn.com/B07XY2STMF | Tracks time to correspond to data
Jumper Wires | Amazon | 120 | 12 | $6.98 | $0.70 | $0.06 | 1 | 10 | 1 | 3 | amzn.com/B01EV70C78 | Electrical connections; avoid soldiering
CR2032 Battery | Amazon | 20 | 1 | $5.99 | $0.30 | $0.30 | 1 | 20 | 1 | 13 | amzn.com/B01G1DRQF6 | Power for Real Time Clock
Micro SD Memory Card | Amazon | 5 | 1 | $15.00 | $3.00 | $3.00 | 1 | 5 | 2 | 3 | amzn.com/B08KSSX9PH | Records sensor data and connects to computer to get logged data
USB Power Bank Battery 5V | Amazon | 2 | 1 | $13.99 | $7.00 | $7.00 | 0 | 2 | 4 | 1 | amzn.com/B08T8TDS8S | Rechargable power supply for Arduino and Sensor, allows for operation without connection to wall socket or computer.
[Optional] 16x2 LCD Display | Adafruit | 1 | 1 | $10.95 | $10.95 | $10.95 | 0 | 1 | 7 | 0 | www.adafruit.com/product/1447 | Display to show current reading without connecting to computer. Optional because sensor functions without this part but students may find it helpful to have instant feedback.
Small Box | DIY / Maker Lab | 1 | 1 | $0.00 | $0.00 | $0.00 | 0 | 1 | 7 | 0 |  | Housing to protect sensor and components. 3D print or build out of cardboard. May also cut holes in small (~12*10*4cm) cardboard box. Design may vary.
ENTER QTY |  |  | Cost Per Sensor |  | $94.03 |  |  |  |  |  |  | Complete Sensor
7 |  |  | Cost of Required Components |  | $76.08 |  |  |  |  |  |  | Only the parts needed to get a barebones setup working off of a computer.
 |  |  | Total Cost |  | $711.42
 |  |  | Extra Part Value |  | $47.95

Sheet: 10+ Units
CO2 Sensor Bill of Materials | Optimized for manufacture of 10+ Units |  |  | Prepared by Brian Woo-Shem and Eric Woo-Shem
Item | Vendor | Qty Included | Qty per Sensor | Product Cost | Sensor Cost | Per Part Cost | Req? | #Sens | QTY to Purchase | Extra | URL | Notes
Arduino Nano (Generic) | Amazon | 3 | 1 | $16.99 | $5.66 | $5.66 | 1 | 3 | 4 | 2 | amzn.com/B07G99NNXL | Microcontroller
Mini Breadboard | Amazon | 12 | 2 | $8.05 | $1.34 | $0.67 | 1 | 6 | 2 | 2 | amzn.com/B08BHRVGMN | Arduino pin base (avoid soldiering)
SCD-30 NDIR CO2 Sensor | Adafruit | 1 | 1 | $53.06 | $53.06 | $53.06 | 1 | 1 | 10 | 0 | www.adafruit.com/product/4867 | Sensor - Bulk discount of $53.06 per unit for 10-99 units, and $47.16 for 100+ units
STEMMA QT Cable Headers for SCD-30 | Adafruit | 1 | 1 | $0.86 | $0.86 | $0.86 | 1 | 1 | 10 | 0 | www.adafruit.com/product/4209 | Cable specific to this sensor (avoid soldiering) - Bulk discount of $0.86 per unit for 10-99 units, and $0.76 for 100+ units
Micro SD Card Adapter Module | Amazon | 3 | 1 | $6.99 | $2.33 | $2.33 | 1 | 3 | 4 | 2 | amzn.com/B08XPFYBYT | Adapter for card recording sensor data and connects to computer to get logged data
DS3231 Real Time Clock Module | Amazon | 5 | 1 | $14.25 | $2.85 | $2.85 | 1 | 5 | 2 | 0 | amzn.com/B07XY2STMF | Tracks time to correspond to data
Jumper Wires | Amazon | 120 | 20 | $6.98 | $1.16 | $0.06 | 1 | 6 | 2 | 2 | amzn.com/B01EV70C78 | Electrical connections; avoid soldiering
CR2032 Battery | Amazon | 20 | 1 | $5.99 | $0.30 | $0.30 | 1 | 20 | 1 | 10 | amzn.com/B01G1DRQF6 | Power for Real Time Clock
Micro SD Memory Card | Amazon | 5 | 1 | $15.00 | $3.00 | $3.00 | 1 | 5 | 2 | 0 | amzn.com/B08KSSX9PH | Records sensor data and connects to computer to get logged data
USB Power Bank Battery 5V | Amazon | 2 | 1 | $13.99 | $7.00 | $7.00 | 0 | 2 | 5 | 0 | amzn.com/B08T8TDS8S | Rechargable power supply for Arduino and Sensor, allows for operation without connection to wall socket or computer.
[Optional] 16x2 LCD Display | Adafruit | 1 | 1 | $9.86 | $9.86 | $9.86 | 0 | 1 | 10 | 0 | www.adafruit.com/product/1447 | Display to show current reading without connecting to computer. Optional because sensor functions without this part but students may find it helpful to have instant feedback. Bulk Discount $9.86 for 10-99, $8.76 for 100+
Small Box | DIY / Maker Lab | 1 | 1 | $0.00 | $0.00 | $0.00 | 0 | 1 | 10 | 0 |  | Housing to protect sensor and components. 3D print or build out of cardboard. May also cut holes in small (~12*10*4cm) cardboard box. Design may vary.
ENTER number of sensors below: |  |  | Cost Per Sensor |  | $87.42 |  |  |  |  |  |  | Complete Sensor
10 |  |  | Cost of Required Components |  | $70.57 |  |  |  |  |  |  | Only the parts needed to get a barebones setup working off of a computer.
 |  |  | Total Cost |  | $898.22
 |  |  | Extra Part Value |  | $20.44

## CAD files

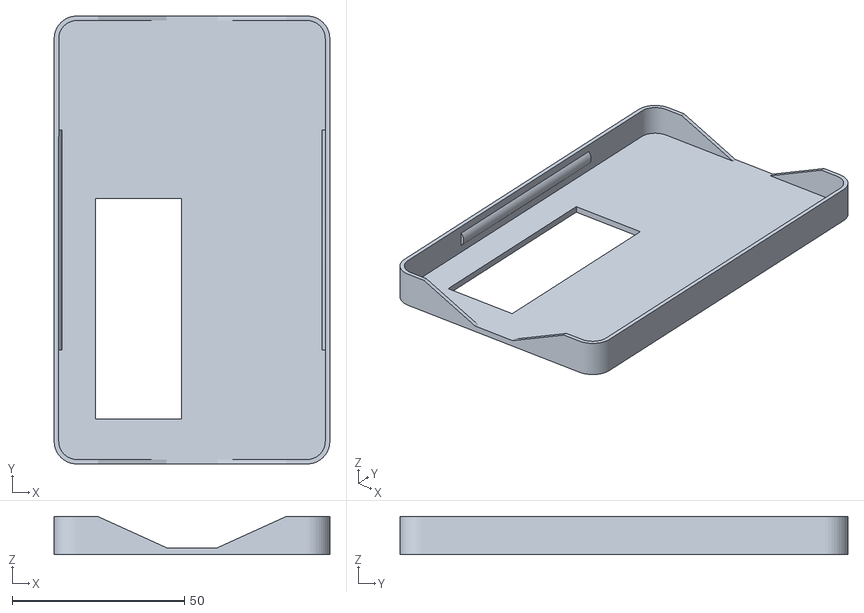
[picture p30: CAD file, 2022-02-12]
3D_Printable_Cases/DIY_CO2_Monitor_Lid_Small_v8.stl
80.0 x 130.0 x 11.1

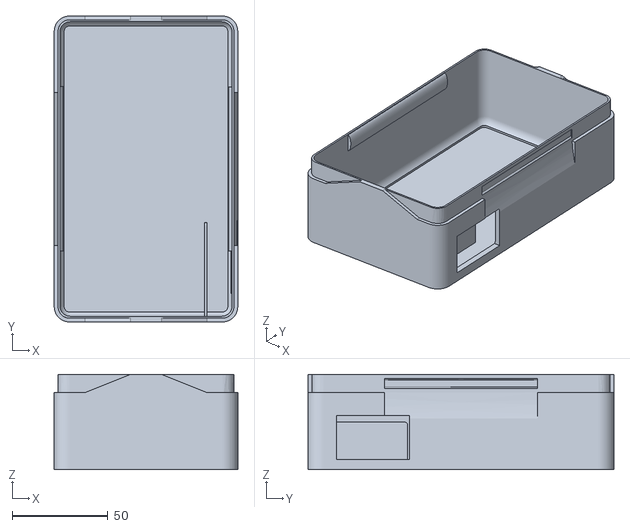
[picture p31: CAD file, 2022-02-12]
3D_Printable_Cases/DIY_CO2_Monitor_Case_Large_v8.stl
96.0 x 160.0 x 49.8

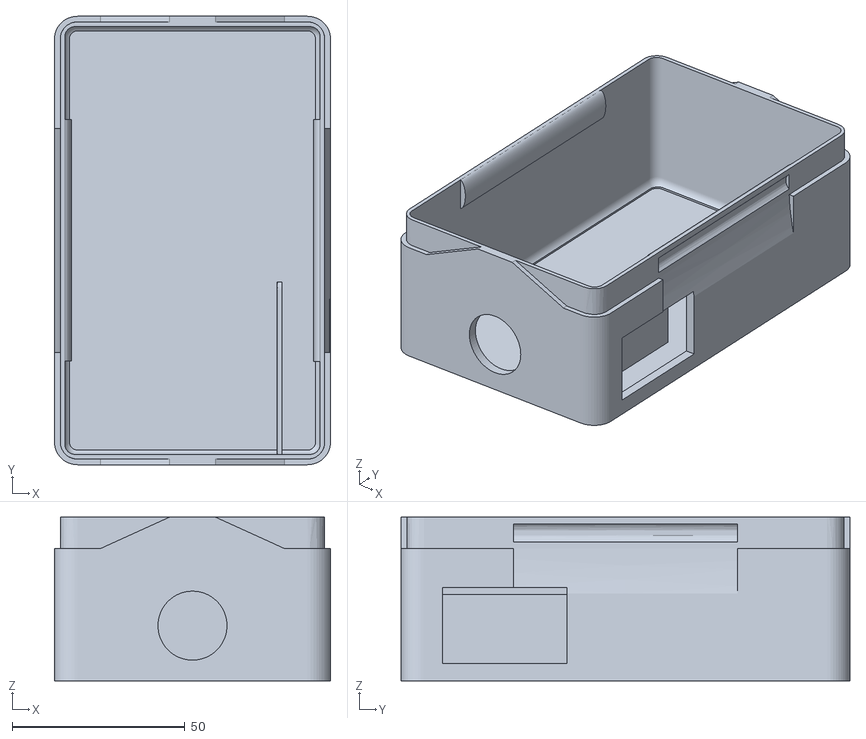
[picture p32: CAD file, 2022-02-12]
3D_Printable_Cases/DIY_CO2_Monitor_Case_Small-HoleSensorSide_v8.stl
80.0 x 130.0 x 47.4

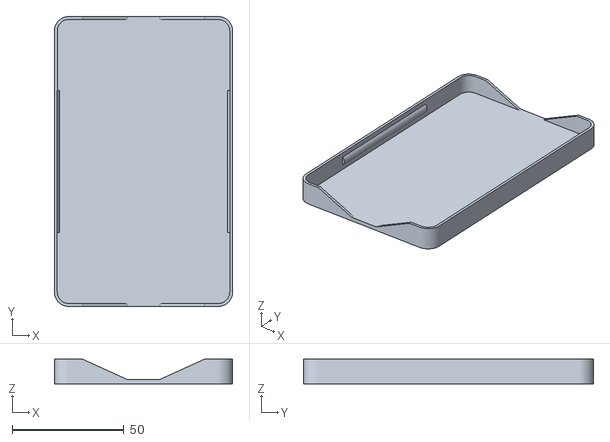
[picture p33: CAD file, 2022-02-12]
3D_Printable_Cases/DIY_CO2_Monitor_Lid_Small_NoScreen_v8.stl
80.0 x 130.0 x 11.1

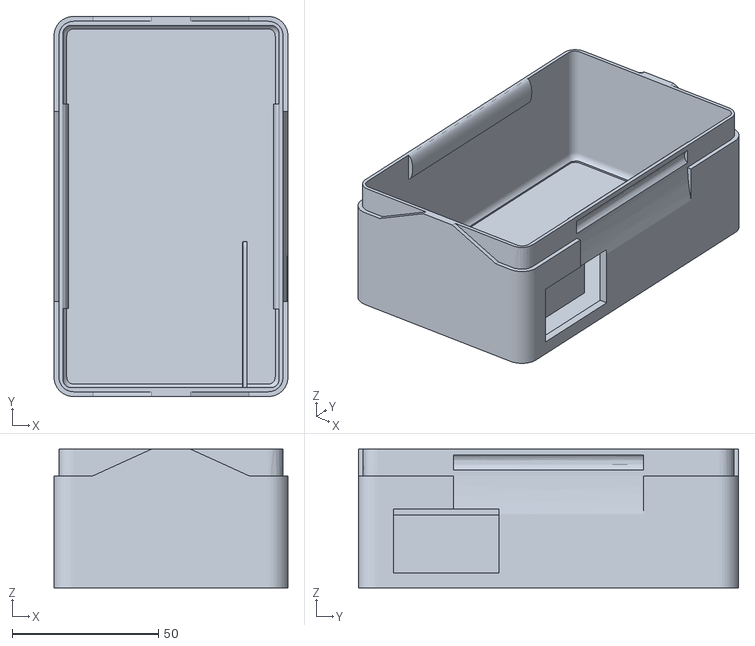
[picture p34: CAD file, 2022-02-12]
3D_Printable_Cases/DIY_CO2_Monitor_Case_Small_v8.stl
80.0 x 130.0 x 47.4

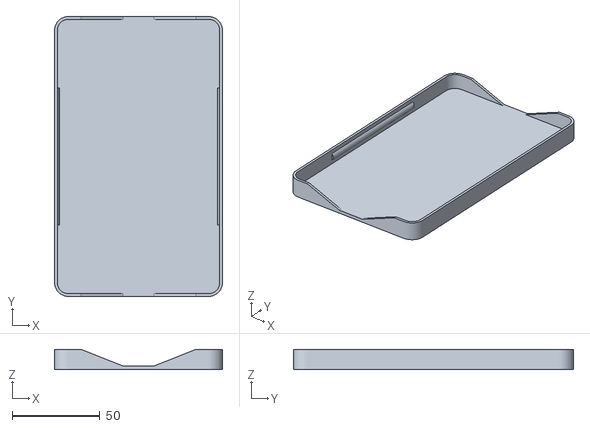
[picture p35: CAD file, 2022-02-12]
3D_Printable_Cases/DIY_CO2_Monitor_Lid_Large_NoScreen_v8.stl
96.0 x 160.0 x 11.6

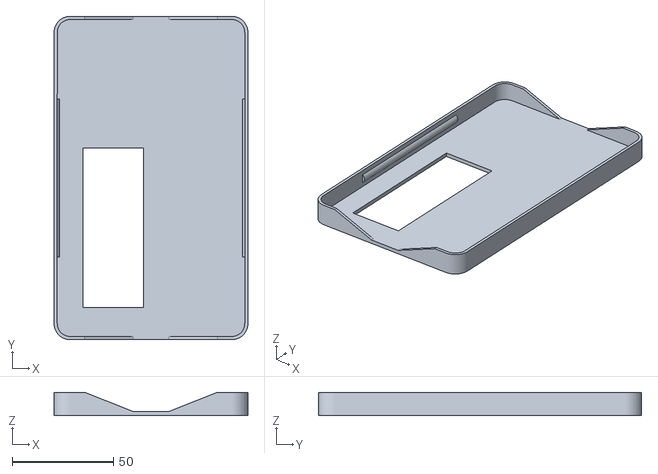
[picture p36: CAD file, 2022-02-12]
3D_Printable_Cases/DIY_CO2_Monitor_Lid_Large_v8.stl
96.0 x 160.0 x 11.6

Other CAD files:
3D_Printable_Cases/DIY_CO2_Monitor_Case_Small-HoleScreenSide_v8.stl

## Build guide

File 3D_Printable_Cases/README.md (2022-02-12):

# 3D Printable Cases for DIY Frugal Arduino CO2 Sensor

CC BY-NC-SA [Brian Woo-Shem](https://www.brianwooshem.com) & [Eric Woo-Shem](https://github.com/ericwooshem)

## Files

`DIY_C02_Monitor_Case_SIZE-PARAMETERS_v#`

#### SIZE

**Small**: 130x80x48mm. For our sensors, the main power battery is outside of the case. Tested and works.

**Large**: 160x96x50mm. Designed for fully-contained sensors where all componenents including the battery fit inside the box. Not yet tested.

#### PARAMETERS

**Hole-** Has additional hole for running a USB cable into the box for power. Only really needed on the small boxes.

**-ScreenSide**: Hole is on side where we put the screen

**-SensorSide**: Hole is on the side where the sensor is mounted

**NoScreen**: Removed hole for the screen. Useful if you choose not to have a screen, or want to operate in stealth mode. 

#### 'v#'

Version number. Current version is v8 as of 2022-02-11.

# Printing

Recommended Settings: Worked for generic Prusa-type printer and Cura
- Material: Generic PLA
- Color: Does not matter, but we prefer if each pair of case and lid are the same color if possible.
- Profile: Draft (Extra Fast would probably work too)
- Infill: 10%, Grid
- Support: Yes, density 10%, grid. Only needed for the one rectangular hole, so I used an overhang angle of 55 and - Minimum Support Area = 26mm^2 to avoid putting supports on the letters.
- Adhesion: Skirt
- To reduce the amount of filament use Wall Line Count = 2 and Top Layers and Bottom Layers = 3. If filament is not a concern, use the defaults in Cura.

# Credits

The main CAD is forked from: 
"Parts Box With Notched Lid" by theronin, licensed under the Creative Commons - Attribution - Share Alike license. See the original at: https://www.thingiverse.com/thing:812074

Modifications CC BY-NC-SA [Brian Woo-Shem](https://www.brianwooshem.com) & [Eric Woo-Shem](https://github.com/ericwooshem)

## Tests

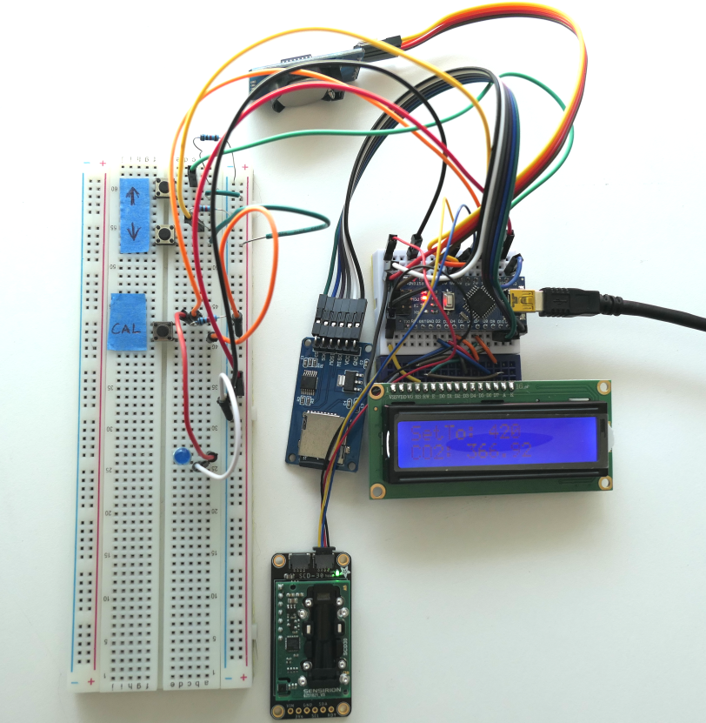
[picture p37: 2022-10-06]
Graphics/CO2_Recalibrator_Tool.png

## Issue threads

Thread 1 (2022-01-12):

Bill of materials has dead links

bwooshem, 2022-01-12:
TODO: Update to include extra parts
TODO: Fix ebay links
TODO: Move to better link we found

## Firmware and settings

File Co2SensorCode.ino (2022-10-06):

/*  DIY Frugal Arduino CO2 Sensor Code
 *  
 *  (C) 2022 Eric Woo-Shem
 *  Version 5.2, updated 2022-10-05
 *  
 *  https://github.com/ericwooshem/DIY-Frugal-Arduino-CO2-Sensor
 *  
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
 *  This program is distributed in the hope that it will be useful, but WITHOUT ANY WARRANTY; without 
 *  even the implied warranty of MERCHANTABILITY or FITNESS FOR A PARTICULAR PURPOSE. See the 
 *  GNU General Public License at https://www.gnu.org/licenses/gpl-3.0.en.html for more details.
  */

/*
Info:
RTC = Real Time Clock
LCD = Liquid Crystal Display (Screen)

Time given will be in military time (24 hour clock)

Resources Used:
https://learn.adafruit.com/adafruit-scd30
https://www.circuitbasics.com/writing-data-to-files-on-an-sd-card-on-arduino/
https://arduinogetstarted.com/tutorials/arduino-rtc
https://github.com/adafruit/RTClib/tree/master/examples
*/
#include <Adafruit_SCD30.h> 
#include <SD.h>
#include "RTClib.h"
#include <LiquidCrystal.h>
//~~~~~~~~~~~~~~~~~~~~~~~~~~~~~~~// ^Import Packages^
LiquidCrystal lcd(9, 8, 5, 4, 3, 2); // Set LCD Screen pins
Adafruit_SCD30  scd30; // Define Sensor
RTC_DS1307 rtc; // Define RTC (Real Time Clock)
/*~~~~~~~~~~~~~~~~~~~~~~~~~~~~~~~*/
File myFile; // Define file "myFile"
String fileName = "CO2_Data.txt"; // Set variable holding filename (You can change the filename)
const int debug = 1; // Set to 1 for console debugging
const int readDelay = 100; // in ms. How long to wait between readings in addition to sensor reset time of 1-2s.
/*~~~~~~~~~~~~~~~~~~~~~~~~~~~~~~~*/
void setup() { // Start setup
  if (debug==1) // If in debug mode
    {
    Serial.begin(115200); // Begin Serial (On computer for debug)
    while (!Serial); // Wait until Serial is started
    }

  lcd.begin(16, 2); // Set size of LCD screen
  pinMode(6, OUTPUT); // Set what pin 6 does (output)
  pinMode(7, OUTPUT); // Set what pin 7 does (output)
  if (! rtc.begin()) { // If fail to begin the RTC (Real Time Clock)
    Serial.println("Couldn't find RTC"); // Print through serial
    abort(); // Stop program
  }
  scd30.begin(); // Start CO2 Sensor
  SD.begin(10); // Start SD card reader/writer
  myFile = SD.open(fileName, FILE_WRITE); // Create or open a the file with name specified above as filename
  DateTime time = rtc.now(); // Get current time
  Serial.println(time.timestamp(DateTime::TIMESTAMP_DATE)); // Print time
  Serial.println(time.timestamp(DateTime::TIMESTAMP_TIME)); // Print date
  myFile.println(time.timestamp(DateTime::TIMESTAMP_DATE)); // Write date to SD card file
  myFile.close(); // Close file to save
  digitalWrite(7, HIGH); // Set LCD brightness, you can change it if you want to
  analogWrite(6, 120); // Setting LCD contrast, you can change it if you want to
  lcd.setCursor(0,0);
  lcd.print("DIY CO2 Monitor");
  lcd.setCursor(0,1);
  lcd.print("Firmware V.5.2");
  delay(1500);
  lcd.clear();
  lcd.setCursor(0,0);
  lcd.print("(C)Eric Woo-Shem");
  delay(1500);
  lcd.clear();
} // End setup
/*~~~~~~~~~~~~~~~~~~~~~~~~~~~~~~~*/
void loop() { // Start loop (forever)
  if (scd30.dataReady()){ // If CO2 data
    if (!scd30.read()) //If probelm reading data
      {
        Serial.println("Sensor Error"); // Print to serial
        return; // Don't do the the following ↓↓↓
       }
    if (debug==1) // If in debug mode
    {
      Serial.println("Temperature (C): "+String(scd30.temperature)); // Print temperature in celsius
      Serial.println("Relative Humidity: "+String(scd30.relative_humidity)+"%"); // Print humidity %
      Serial.println("CO2: "+String(scd30.CO2)+" ppm"); // Print CO2 ppm (Parts Per Million)
      Serial.println();
    }
    myFile = SD.open(fileName, FILE_WRITE); // Open file
    DateTime time = rtc.now(); // Get current time
    myFile.println(time.timestamp(DateTime::TIMESTAMP_TIME)+"; "+(scd30.CO2)); // Write the time, followed by the CO2 level, separated by a semi-colon (;)
    myFile.close(); // Close file (Save file)
    lcd.setCursor(0,0); // Set LCD Screen cursor position
    lcd.print(time.timestamp(DateTime::TIMESTAMP_TIME)); // Write the time to LCD Screen 
    lcd.setCursor(0,1); // Set LCD Screen cursor position
    lcd.print("CO2: "+String(scd30.CO2)); // Write the CO2 level to the LCD Screen
  } // End "If CO2 data"
  delay(readDelay);
} // End loop

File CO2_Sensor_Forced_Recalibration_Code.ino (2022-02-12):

// DIY CO2 Sensor SCD-30 Forced Recalibration Code
// CC By-NC 2022 Eric & Brian Woo-Shem
/*
Info:
Code to quickly recalibrate a SCD-30 sensor using Arduino. If sensor is not returning values around 400-450ppm when outside, use this code to reset it.
Also disables automatic self-calibration because it has caused problems.
Afterward it will take measurements and display them to screen indefinitely so you can check your work. 
Does NOT log data. Does NOT use RTC.

LCD = Liquid Crystal Display (Screen)


Resources Used:
https://learn.adafruit.com/adafruit-scd30
*/
#include <Adafruit_SCD30.h> 
#include <LiquidCrystal.h>
//~~~~~~~~~~~~~~~~~~~~~~~~~~~~~~~// ^Import Packages^
LiquidCrystal lcd(9, 8, 5, 4, 3, 2); // Set LCD Screen pins
Adafruit_SCD30  scd30; // Define Sensor

/*~~~~~~~~~~~~~~~~~~~~~~~~~~~~~~~*/
void setup() { // Start setup

  lcd.begin(16, 2); // Set size of LCD screen
  pinMode(6, OUTPUT); // Set what pin 6 does (output)
  pinMode(7, OUTPUT); // Set what pin 7 does (output)
  
  digitalWrite(7, HIGH); // Set LCD brightness, you can change it if you want to
  analogWrite(6, 120); // Setting LCD contrast, you can change it if you want to
  
  scd30.begin(); // Start CO2 Sensor
  
// Force sensor to grab a few measurements to deal with first value = zero and sensor startup time bug.
  int i = 1;
  while(i<4){
    if (scd30.dataReady()){ // If CO2 data
        if (!scd30.read()) //If probelm reading data
          {
            return; // Don't do the the following ↓↓↓
           }
        lcd.clear();
        lcd.setCursor(0,0); // Set LCD Screen cursor position
        lcd.print("Calibrating..."); // Write the time to LCD Screen 
        lcd.setCursor(0,1); // Set LCD Screen cursor position
        lcd.print("Co2: "+String(scd30.CO2)); // Write the CO2 level to the LCD Screen
    }
    i += 1;
  }
  delay(1000);

// Disable automatic self-calibration because it tends to make sensors get off over time
// Note: if set to true, self-calibration is enabled.
  scd30.selfCalibrationEnabled(false);

// Force recalibration to approximate current outdoor value
// ONLY DO THIS WHEN OUTSIDE AND SENSOR IS AWAY FROM PEOPLE, WIND, AND OTHER SOURCES OF ERROR
// Typical outdoor value is 410-440ppm. 
// Comment out to only disable self-calibration
  scd30.forceRecalibrationWithReference(425); //IMPORTANT CHANGE THIS VALUE TO YOUR EXPECTED VALUE

} // End setup
/*~~~~~~~~~~~~~~~~~~~~~~~~~~~~~~~*/

void loop() {
  // Repeatedly read in values once the calibration is complete. So you can check the sensor if you have LCD connected.
  if (scd30.dataReady()){ // If CO2 data
    if (!scd30.read()) //If probelm reading data
      {
        return; // Don't do the the following ↓↓↓
       }
    lcd.clear();
    lcd.setCursor(0,0); // Set LCD Screen cursor position
    lcd.print("Calibration Done"); // Different first line message to indicate it is running calibration code.
    lcd.setCursor(0,1); // Set LCD Screen cursor position
    lcd.print("Co2: "+String(scd30.CO2)); // Write the CO2 level to the LCD Screen
  }
}

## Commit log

2022-01-09 Working sensor code
2022-01-09 Complete sensor pictures
2022-01-09 Arduino upload screenshot
2022-01-09 Documentation for sensor updates
2022-01-09 Bill of materials (same except for file format)
    [CO2_Sensor_Bill_of_Materials.ods, CO2_Sensor_Bill_of_Materials.xlsx]
2022-02-08 Version 5.1. Fixed first value = 0 bug
    [Co2SensorCode.ino]
2022-02-12 SCD-30 Calibration Code
2022-02-12 Custom Sensor Cases w/ Snap-Close lid
    [DIY_CO2_Monitor_Case_Large_v8.stl, DIY_CO2_Monitor_Case_Small-HoleScreenSide_v8.stl, DIY_CO2_Monitor_Case_Small-HoleSensorSide_v8.stl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]
2022-02-12 3D Printable Cases - Fix Readme
2022-10-06 V5.2. Minor bug fixes
    [Co2SensorCode.ino]

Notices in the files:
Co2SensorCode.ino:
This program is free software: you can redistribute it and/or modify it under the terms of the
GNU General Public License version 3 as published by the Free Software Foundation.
